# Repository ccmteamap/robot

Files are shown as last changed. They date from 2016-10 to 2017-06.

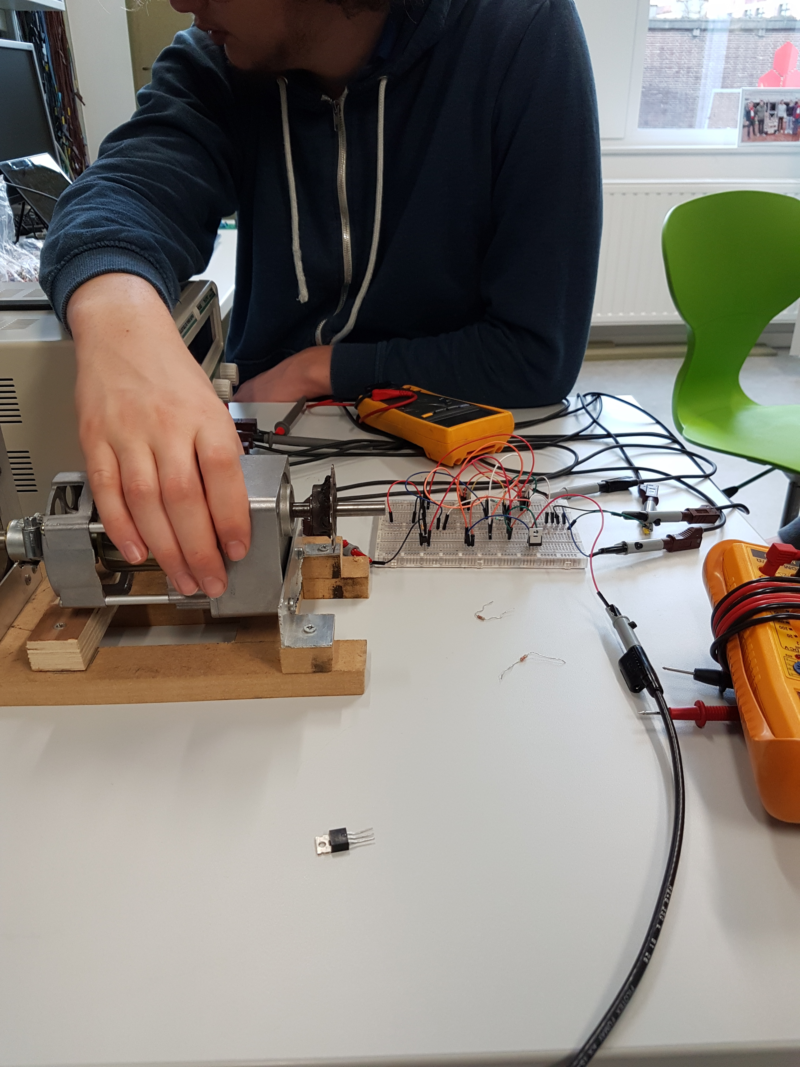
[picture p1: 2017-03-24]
docs/photos/IMG_20170320_091853.jpg

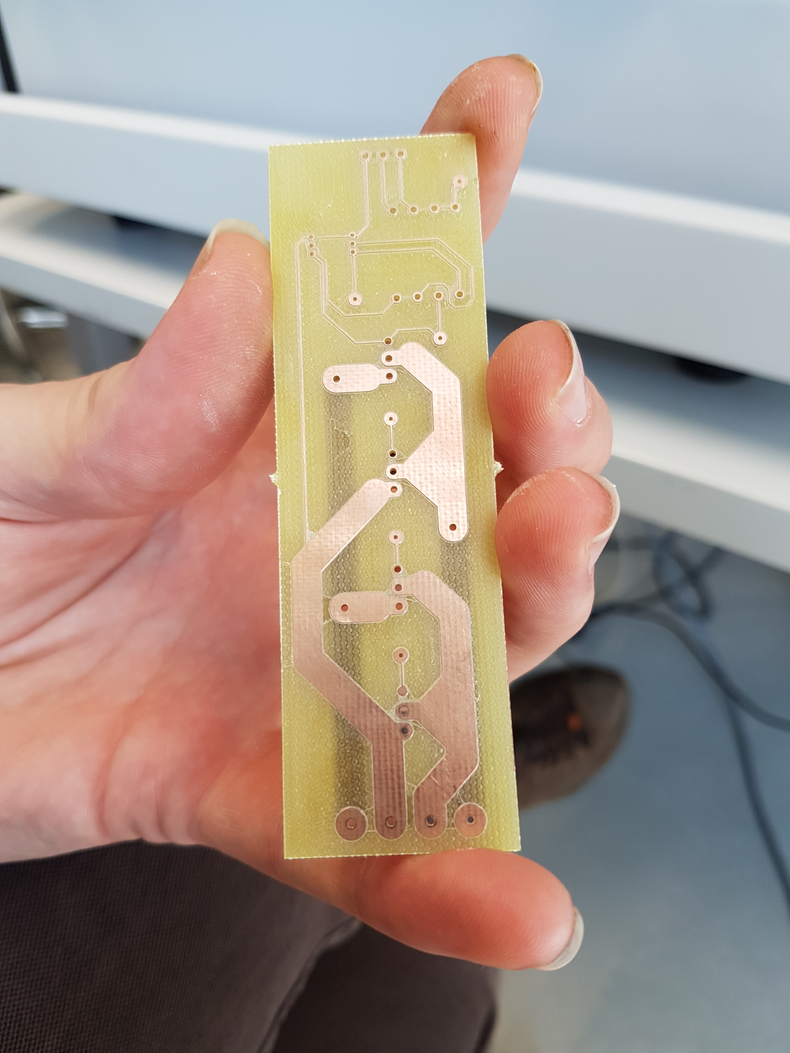
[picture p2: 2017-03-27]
docs/photos/20170327_143319.jpg

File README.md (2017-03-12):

# Project team CCMAP
## Project description
Design and build a robot that drives from the starting position to the water source on the other side of the contest area and fill  bucket with water, drive the bucket with water back through the contest area which has obstacles on the floor and deposit the water in the water collection tower on the “fire” location.
The robot must be working autonomously when it is in the contest area. It is not allowed to “help” the robot while in the contest area. If the robot gets stuck the teams are allowed to stop the robot and move the robot back to the start position from which the robot can be restarted with an empty bucket. The robot can make multiple runs collecting and delivering water within the duration of 5 minutes. The water must be transported in an open bucket, covering the bucket is not allowed, it is not allowed to re-use water spilled from the bucket. It is only allowed to transport the water inside the bucket. 

[More info](http://www.ccm.nl/en/assignment-2017/assignment-2017.html)

## Our team

  We have divided our team into 3 subgroups:
  
  **Driving**
  
  Ski De Keersmaecker
  
  Ruven Salamon
  
  **Bucket**
  
  Robbe Goethals
  
  Wouter Peetermans
  
  **Pump**
  
  Koen Schauwaert
  
  Maarten Wachters

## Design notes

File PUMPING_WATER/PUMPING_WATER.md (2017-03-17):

#TODO

#GOALS

1. Pump water from basin into bucket (without touching the bucket)
2. Transport the water to the other bucket
3. Lifting system that allows the bucket to be lifted and tilted

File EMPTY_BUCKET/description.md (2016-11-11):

#General
This part of the robot will have to empty the bucket, filled with water by the pump, in a reservoir.
The bucket will be attached to some kind of rollercoastercar.
The car will be pulled upwards with the DC-motor using bearings and two rails.

#Design
The rails in wich the car moves will go straight up.
At the end of the rails, they will bend over the reservoir so the bucket can be emptied.
Because the bucket is fixed to the moving car, the bend will enable us to empty the bucket.

#Software

##Master-Arduino
The Arduino used for driving the robot (master)  will communicate to the Arduino for emptying the bucket (slave).
When the master knows that the robot is standing against the reservoir using distance sensors, it will send a signal to the slave so that the filled bucket can be emptied.

##Slow start
To make sure we don't spill a lot of water, the start of the emptying-part will be slow. The motor will start pulling the car upwards.

##Middle
Because time is essential in this assignment, we have a powerfull motor that can pull the bucket fastly to the bended part in the rails.

##Emptying
When the bucket is at the bended part of the rails, water will begin to be poured out of the bucket.
The motor will then slowly pull the car until the end of the rail is reached so the water is poured in the reservoir and nothing is spilled over.

##Empty bucket
When there's no more water in the bucket, the microcontroller will have to send a signal to the master so that the robot can already drive towards the water supply.
While driving, the bucket will be let down back to it's original place.
When the bucket is down, the Arduino will again send a signal to the master so that the master can let the pump fill the bucket again.

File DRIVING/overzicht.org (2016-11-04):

* Onderstel
** MateriaalLijst
- 2 moteren
- 4 wielen (met lagers ?)
- 4 kleine assen
- 2 kettingen / riemen
- 6 afstandsensoren
- arduino's
  - 1 master/emmer/pomp;
  - 1 per 2 sensoren
  => 4 arduino's
- 4 lagers
** Onderdelen
*** Seriële communicatie [0/2]
    - [ ] Protocol kiezen.
      * I2C
      * SPI
    - [ ] Protocol uittesten.	
    - [ ] Custom library schrijven.
*** Sensoren [2/4]
    - [X] Soort sensor kiezen en testen.
      * Ultrasoon
      * Infrarood
    - [X] Opstelling kiezen.
    - [ ] Library schrijven.
      * Cache systeem om foutieve waardes weg te gooien.x
    - [ ] Reactieruimte voor verschillende snelheden bij verschillende hoeken berekenen.
*** Wielaandrijving [/]
*** Frame [0/3]
    - [ ] Wielen kiezen
    - [ ] Ontwerp uittekenen.
      * gewicht andere modules inschatten
      * Monteerpunten voor emmer en pomp
      * Bekabeling
      * Batterij
      * Motor
      * Aandrijving
      * Wielen
      * Sensoren

* TEAMS

| TEAMS | Onderstel | Emmer  | Pomp    |
|-------+-----------+--------+---------|
|       | Ruven     | Wouter | Koen    |
|       | Ski       | Robbe  | Maarten |

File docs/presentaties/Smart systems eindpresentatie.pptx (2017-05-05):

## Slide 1

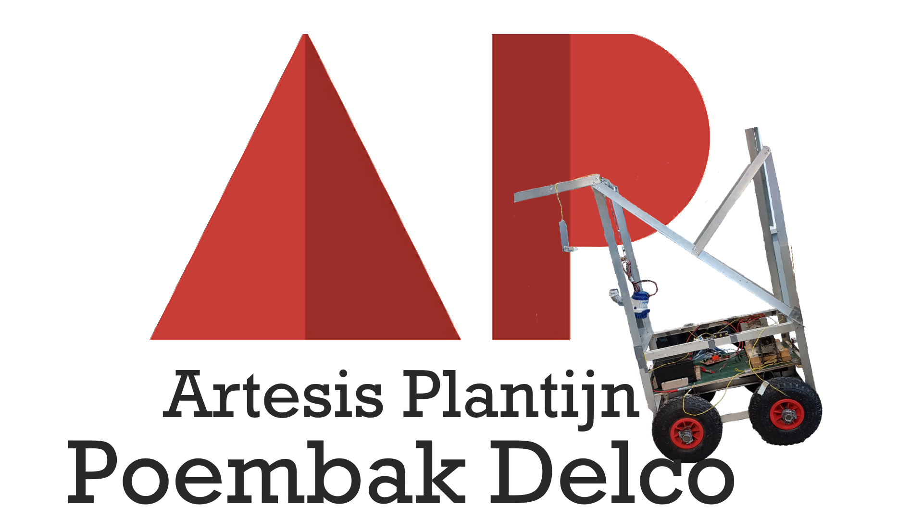
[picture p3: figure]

## Opdracht

## Progress

“Where are ü now” - Diplo

## PCB

## Frame

## Pomp

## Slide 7

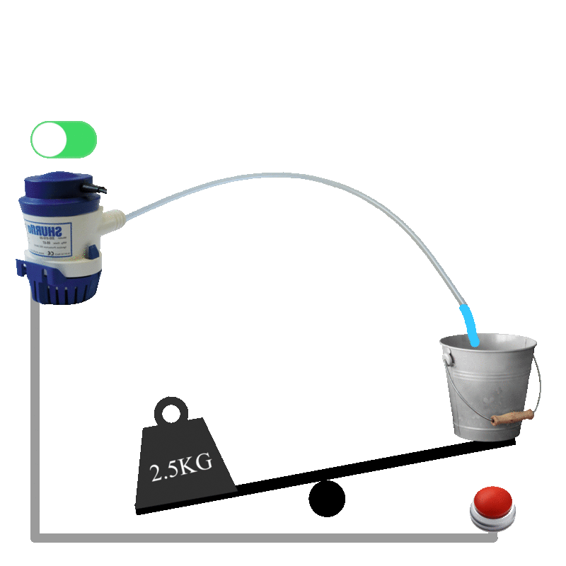
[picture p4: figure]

## Code

## Wedstrijd

CCM/Sioux wedstrijd 17/05/2017

## opdracht

## Opdracht

## Verloop

## Documentatie

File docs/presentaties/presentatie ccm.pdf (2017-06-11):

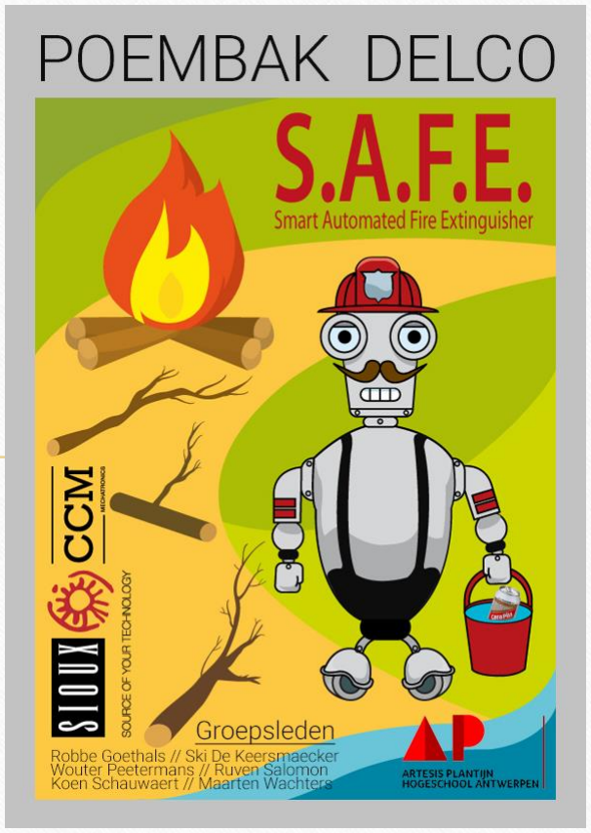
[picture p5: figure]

# Robot CCM

## Poembak delco gaat ervoor

# Analyse probleemstelling

- Hoe krijgen we het water uit de waterbak?
- Hoe krijgen we het water in de emmer?
- Hoe behouden we het water in de emmer tijdens transport?
- Hoe krijgen we het water bij de ‘Fire Location’?
- Hoe rijden we over het parcours?
- Hoe ontwijken we de obstakels?

# Opsplitsing onderdelen

- Team Transport:
- Ruven & Ski
- Aansturen wielen
- Frame
- Team Emmer:
- Wouter & Robbe
- Emmer uitkiepen
- Team Pomp:
- Koen & Maarten
- Emmer vullen

# Team Transport

- 2 krachtige motoren
- Zware schokken opvangen
- Snelheid maken en behouden
- Wielen
- Pros:
- Goedkoop
- Makkelijke implementatie
- Behendig
- Cons:
- Minder schokbestendig

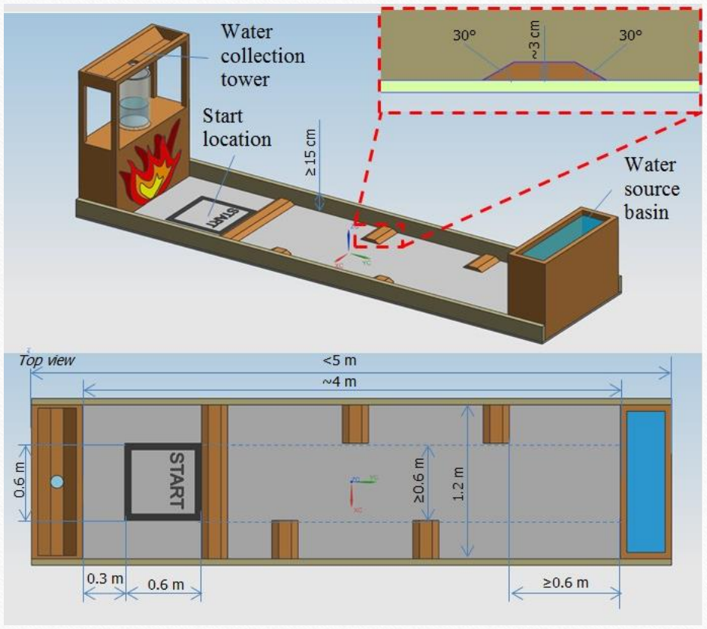
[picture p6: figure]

- Doel:
- Zij obstakels ontwijken
- Robot met wielen max. 50 cm breed
- Groot obstakel afremmen + wielen met dikke banden (schokabsorptie)
- Uitlezen beide basins wanneer stoppen robot en uitkiepen emmer of starten pompen – middels eindloopschakelaar
- 1 minuut per rit: 15 sec. heen en 15 sec. terug: snelheid: 8 meter per 0,5 min = 0,96km/u
- Doel: 2 a 3km/u en afremmen bij obstakel

# Benodigdheden: wat we al hebben

- Motor met reductie voor aandrijving robot
- Assen
- Ketting en tandwielen
- Arduino
- Sensoren

# Benodigdheden: aan te kopen

- Wielen | • 100 euro

# Team Emmer

- Emmer laag in frame voor stabiliteit
- Optakelen via rails (zoals achtbaan: kogellagers klemmen rondom rails)
- Omhoog en omlaag via ketting, aangestuurd door motor
- Bovenaan gebogen rails voor uitschenken emmer

## Test liften emmer

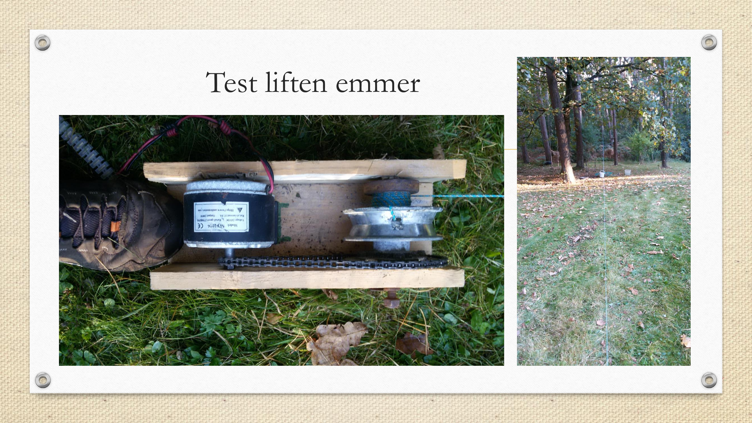
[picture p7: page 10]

# Benodigdheden: wat we al hebben

- Emmer
- Motor voor hijsen van emmersysteem (kar)
- Rails met kogellagers
- Arduino
- Sensoren

# Benodigdheden: aan te kopen

- Niets

# Team Pomp

- Gebruik van dompelpomp
- In basin laten zakken middels katrolsysteem
- Via eindeloopschakelaar in laten pompen en pomp laten zakken wanneer robot tegen basin

# Benodigdheden: wat we al hebben

- Arduino
- Sensoren

# Benodigdheden: aan te kopen

- Dompelpomp
- Katrolsysteem
- Motor
- Tuinslang met koppelstukjes
- 50 euro
- 5 euro
- 100 euro
- 15 euro

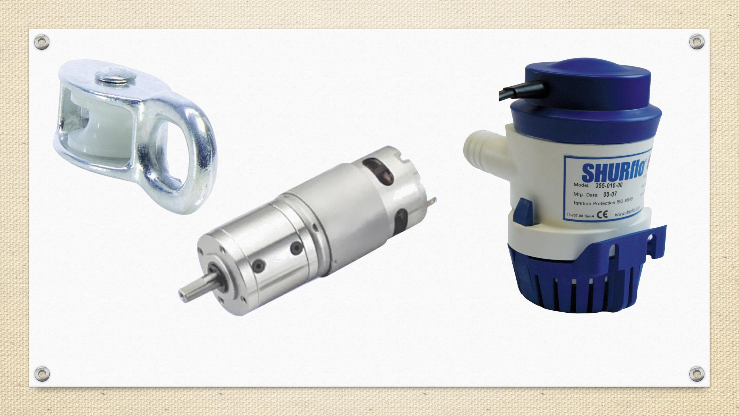
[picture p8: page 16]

# Programmatie

//calculates a new exponential moving average.

unsigned int calcAverage(unsigned int distance, unsigned long average) {

static float smoothingFactor = 2.0 / (SAMPLESIZE + 1.0);

double newAverage = (distance * smoothingFactor) + (average * (1

- smoothingFactor));

return round(newAverage);

}

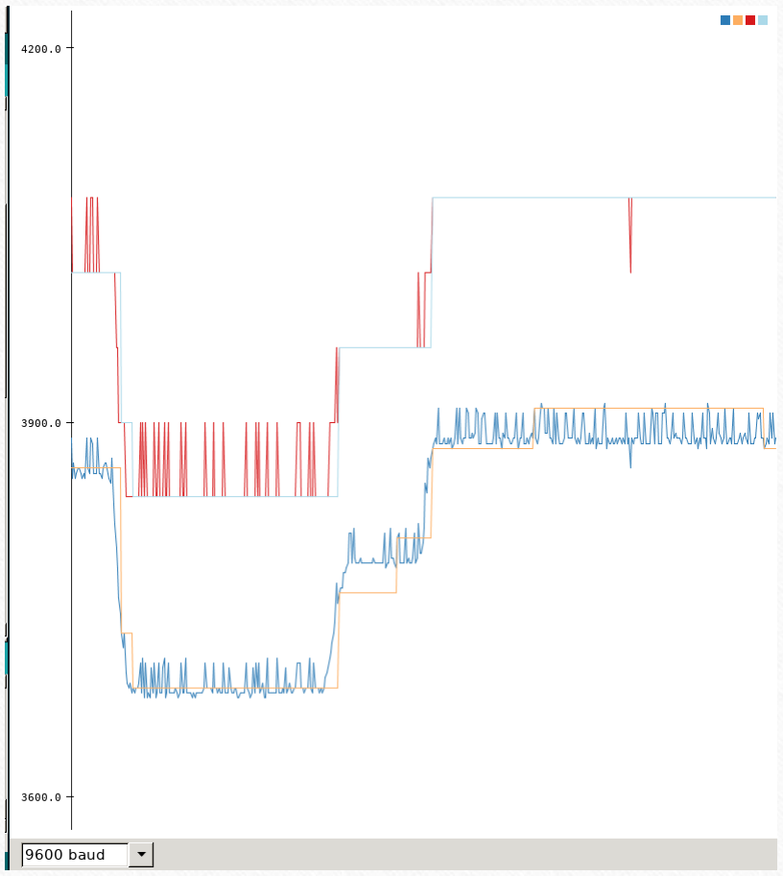
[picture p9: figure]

- Rood: ruwe meting in cm
- Lichtblauw: exponential moving avg.
- Gebruik voor elke sensor

# Benodigdheden: wat we al hebben algemeen

- Groot gedeelte van het frame van vorig jaar
- Arduino
- Sensoren
- Oplader voor de batterijen

# Benodigdheden: aan te kopen algemeen

- Klinknagels
- Deel van het frame
- Batterijen
- Kogellagers reserve
- 35 euro voor 100 stuks
- 100 euro
- 100 euro voor 4 stuks (2 x reserve)
- 36 euro voor 10 stuks

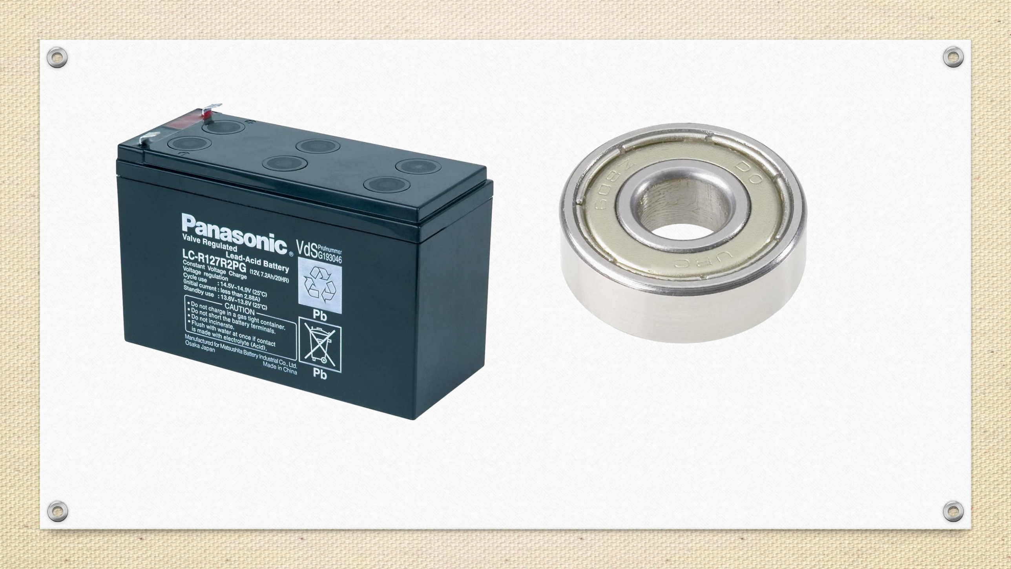
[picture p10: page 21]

# Kostenraming

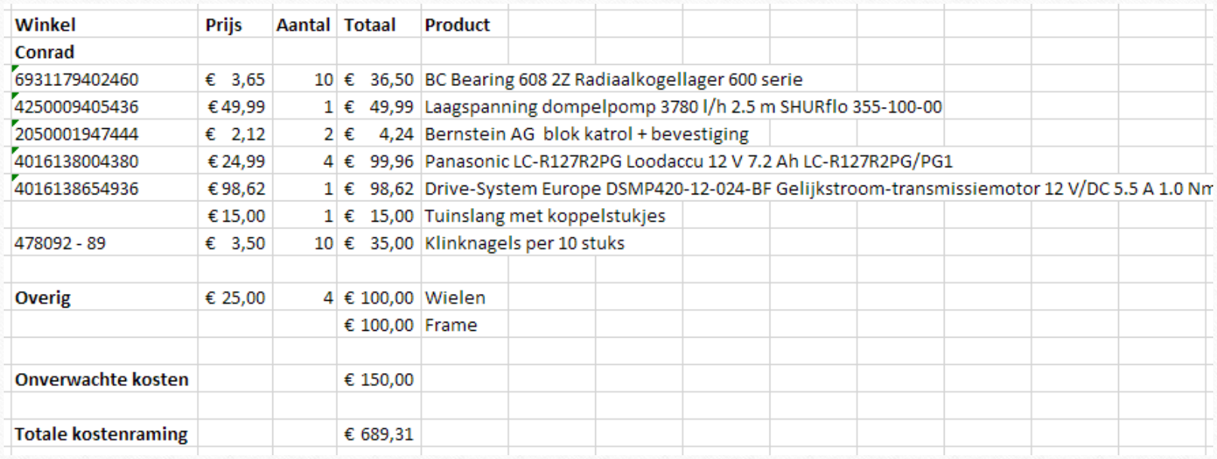
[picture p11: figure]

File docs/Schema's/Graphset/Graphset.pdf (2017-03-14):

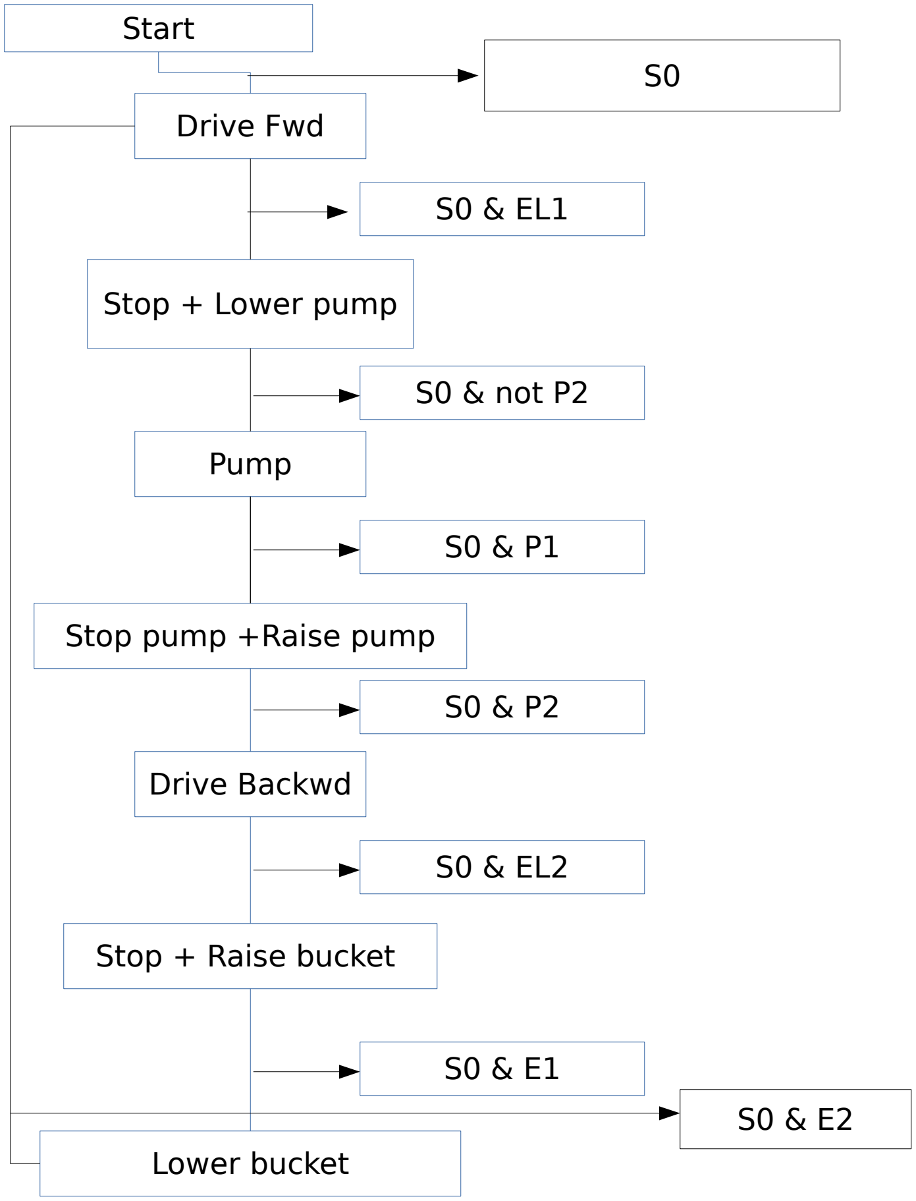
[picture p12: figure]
Drive Fwd; Stop + Lower pump; Pump; Stop pump +Raise pump; Drive Backwd; Stop + Raise bucket; Lower bucket; Start; S0 & not P2

E1: Emmer bovenaan
E2: Emmer onderaan
EL1 : Eindeloopschakelaar emmer zijde EL2: Eindeloopschakelaar pomp zijde P1: Pomp aan emmer
P2: Pomp aan kraan(?)
S0: Start

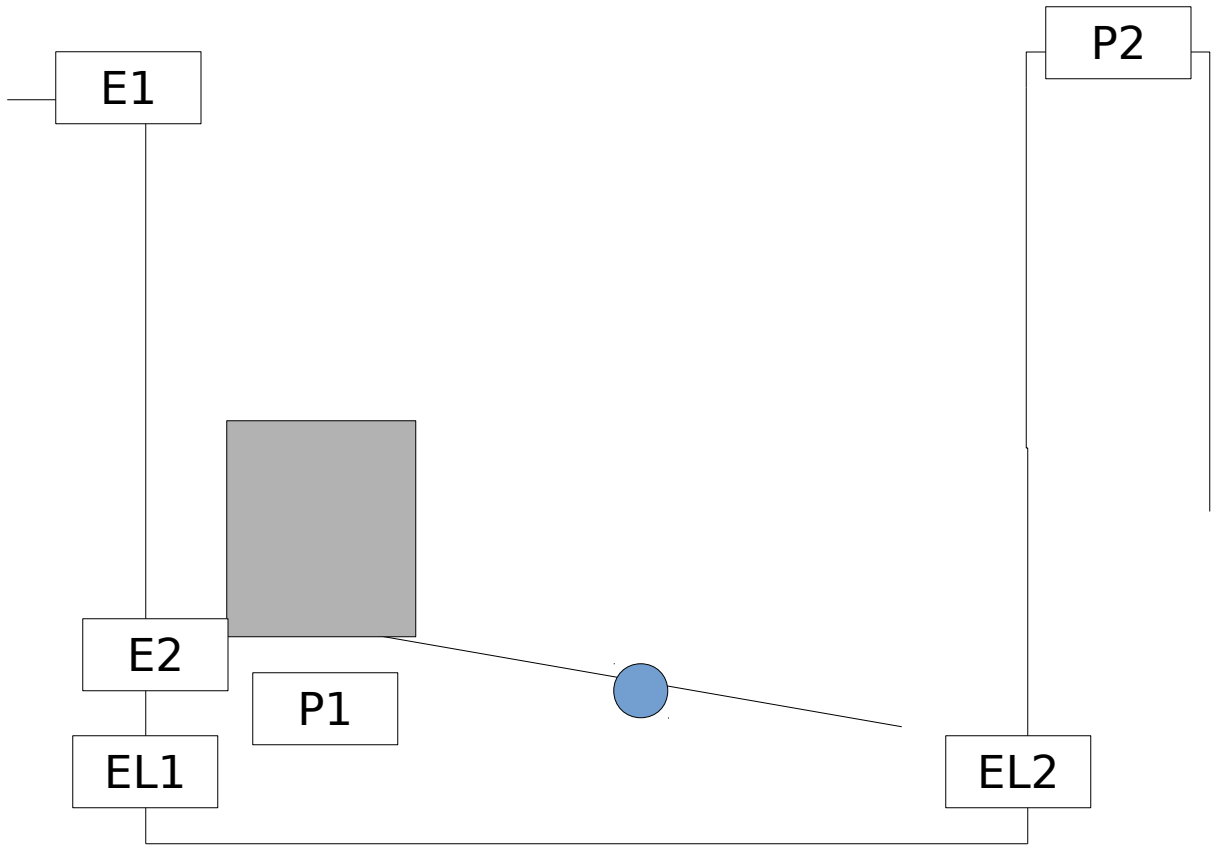
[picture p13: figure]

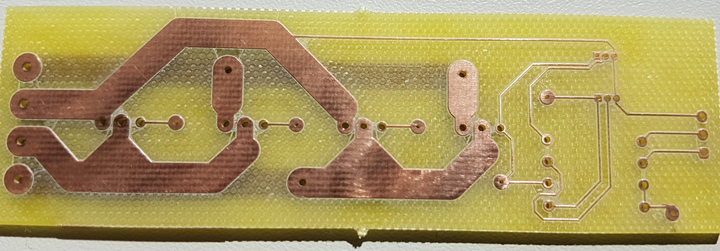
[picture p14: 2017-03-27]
docs/photos/pcb.png

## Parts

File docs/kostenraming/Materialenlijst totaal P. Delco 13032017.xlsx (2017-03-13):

Winkel | Prijs | Aantal | Totaal | Product | URL
Conrad
4250009405436 | €49.99 | 1 | €49.99 | Laagspanning dompelpomp 3780 l/h 2.5 m SHURflo 355-100-00 | https://www.conrad.nl/nl/laagspanning-dompelpomp-3780-lh-25-m-shurflo-355-100-00-551121.html
2050001947444 | €2.12 | 5 | €10.60 | Bernstein AG blok katrol + bevestiging | https://www.conrad.nl/nl/bernstein-ag-bevestiging-voor-blok-katrol-bevestiging-voor-blokkatrol-1-stuks-1164845.html
4016138004380 | €24.99 | 4 | €99.96 | Panasonic LC-R127R2PG Loodaccu 12 V 7.2 Ah LC-R127R2PG/PG1 | https://www.conrad.nl/nl/panasonic-lc-r127r2pg-loodaccu-12-v-72-ah-lc-r127r2pgpg1-loodvlies-agm-b-x-h-x-d-151-x-94-x-65-mm-kabelschoen-48-mm-onderhoudsvrij-vd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
4016138654936 | €98.62 | 1 | €98.62 | Drive-System Europe DSMP420-12-024-BF Gelijkstroom-transmissiemotor 12 V/DC 5.5 A 1.0 Nm 248 omw/min As-diameter: 8 mm Drive-System Europe | https://www.conrad.nl/nl/drive-system-europe-dsmp420-12-024-bf-gelijkstroom-transmissiemotor-12-vdc-55-a-10-nm-248-omwmin-as-diameter-8-mm-191880.html
533468 - 89 | €5.99 | 5 | €29.95 | Weefselslang 1 1/4 inch Transparant | https://www.conrad.nl/nl/weefselslang-1-14-inch-transparant-533468-533468.html
1008392 - 89 | €6.99 | 1 | €6.99 | Sanifri 470010476 Slangklem Set van 10 | https://www.conrad.nl/nl/sanifri-470010476-slangklem-set-van-10-1008392.html
478092 - 89 | €3.50 | 10 | €35.00 | Klinknagels per 10 stuks | https://www.conrad.nl/nl/bralo-klinknagelmoer-roestvrij-staal-platbolkop-ronde-schacht-open-95-mm-roestvrij-staal-aisi-304-10-stuks-478092.html
1005174 - 89 | €4.79 | 1 | €4.79 | Soudal Silirub S Siliconen Kleur: Transparant 310 ml | https://www.conrad.nl/nl/soudal-silirub-s-siliconen-kleur-transparant-310-ml-1005174.html
404198 - 89 | €4.79 | 2 | €9.58 | TOOLCRAFT Gaffer Textieltape Grijs (l x b) 20 m x 48 mm Smeltlijm Inhoud: 1 rollen | https://www.conrad.nl/nl/toolcraft-gaffer-textieltape-grijs-l-x-b-20-m-x-48-mm-smeltlijm-inhoud-1-rollen-404198.html
541124 - 89 | €1.29 | 2 | €2.58 | Conrad Components Isolatietape Zwart (l x b) 10 m x 19 mm Rubber Inhoud: 1 rollen | https://www.conrad.nl/nl/conrad-components-isolatietape-zwart-l-x-b-10-m-x-19-mm-rubber-inhoud-1-rollen-541124.html
600409 - 89 | €1.04 | 10 | €10.40 | LappKabel 0052001 Hoge-temperatuur-draad ÖLFLEX® HEAT 180 SIF 1 x 2.5 mm² Zwart Per meter | https://www.conrad.nl/nl/lappkabel-0052001-hoge-temperatuur-draad-oelflex-heat-180-sif-1-x-25-mm-zwart-per-meter-600409.html
603167 - 89 | €0.94 | 10 | €9.40 | LappKabel 0052104 Hoge-temperatuur-draad ÖLFLEX® HEAT 180 SIF 1 x 2.5 mm² Rood Per meter | https://www.conrad.nl/nl/lappkabel-0052104-hoge-temperatuur-draad-oelflex-heat-180-sif-1-x-25-mm-rood-per-meter-603167.html
1225410 - 89 | €0.18 | 5 | €0.90 | Krimpkous zonder lijm Zwart 1 mm Krimpverhouding:2:1 | https://www.conrad.nl/nl/krimpkous-zonder-lijm-zwart-1-mm-krimpverhouding21-1225410.html
1225442 - 89 | €0.20 | 5 | €1.00 | Krimpkous zonder lijm Zwart 2.50 mm Krimpverhouding:2:1 | https://www.conrad.nl/nl/krimpkous-zonder-lijm-zwart-250-mm-krimpverhouding21-1225442.html
1225453 - 89 | €0.24 | 5 | €1.20 | Krimpkous zonder lijm Zwart 4.50 mm Krimpverhouding:2:1 | https://www.conrad.nl/nl/krimpkous-zonder-lijm-zwart-450-mm-krimpverhouding21-1225453.html
1225446 - 89 | €0.24 | 5 | €1.20 | Krimpkous zonder lijm Rood 4.50 mm Krimpverhouding:2:1 | https://www.conrad.nl/nl/krimpkous-zonder-lijm-rood-450-mm-krimpverhouding21-1225446.html
214477 - 89 | €2.49 | 20 | €49.80 | Radiaal kogellager van chroomstaal 7 mm | https://www.conrad.nl/nl/radiaal-kogellager-van-chroomstaal-7-mm-214477.html
1340437 - 89 | €9.99 | 2 | €19.98 | Loodaccu-lader VOLTCRAFT BC-600 2 V, 6 V, 12 V Loodgel, Loodzuur, Loodvlies | https://www.conrad.nl/nl/loodaccu-lader-voltcraft-bc-600-2-v-6-v-12-v-loodgel-loodzuur-loodvlies-1340437.html
812371 - 89 | €3.29 | 2 | €6.58 | WD40 Company 49201 WD-40 Multi-olie 100 ml | https://www.conrad.nl/nl/wd40-company-49201-wd-40-multi-olie-100-ml-812371.html
478006 - 89 | €2.69 | 2 | €5.38 | Bralo Klinknagel alu/staal platbolkop kleinverpakking 8 mm Aluminium/staal 50 stuks | https://www.conrad.nl/nl/bralo-klinknagel-alustaal-platbolkop-kleinverpakking-8-mm-aluminiumstaal-50-stuks-478006.html
1493521 - 89 | €9.62 | 8 | €76.96 | Panasonic AM1301F Eindschakelaar 250 V/AC 10 A Metalen hefboom, recht schakelend IP40 1 stuks | https://www.conrad.nl/nl/panasonic-am1301f-eindschakelaar-250-vac-10-a-metalen-hefboom-recht-schakelend-ip40-1-stuks-1493521.html
Brico
4001073199208 | €21.24 | 4 | €84.96 | Wagner pneumatisch wiel diam. 200 mm | https://www.brico.be/search?text=Wagner+pneumatisch+wiel+diam.+200+mm
Totale kostenraming |  |  | €615.82

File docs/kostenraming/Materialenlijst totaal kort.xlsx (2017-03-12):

Winkel | Prijs | Aantal | Totaal | Product
Conrad
6931179402460 | €3.65 | 10 | €36.50 | BC Bearing 608 2Z Radiaalkogellager 600 serie
4250009405436 | €49.99 | 1 | €49.99 | Laagspanning dompelpomp 3780 l/h 2.5 m SHURflo 355-100-00
2050001947444 | €2.12 | 2 | €4.24 | Bernstein AG blok katrol + bevestiging
4016138004380 | €24.99 | 4 | €99.96 | Panasonic LC-R127R2PG Loodaccu 12 V 7.2 Ah LC-R127R2PG/PG1
4016138654936 | €98.62 | 1 | €98.62 | Drive-System Europe DSMP420-12-024-BF Gelijkstroom-transmissiemotor 12 V/DC 5.5 A 1.0 Nm 248 omw/min As-diameter: 8 mm Drive-System Europe
533468 - 89 | €5.99 | 5 | €29.95 | Weefselslang 1 1/4 inch Transparant
1008392 - 89 | €6.99 | 1 | €6.99 | Sanifri 470010476 Slangklem Set van 10
478092 - 89 | €3.50 | 10 | €35.00 | Klinknagels per 10 stuks
1005174 - 89 | €4.79 | 1 | €4.79 | Soudal Silirub S Siliconen Kleur: Transparant 310 ml
404198 - 89 | €4.79 | 2 | €9.58 | TOOLCRAFT Gaffer Textieltape Grijs (l x b) 20 m x 48 mm Smeltlijm Inhoud: 1 rollen
541124 - 89 | €1.29 | 2 | €2.58 | Conrad Components Isolatietape Zwart (l x b) 10 m x 19 mm Rubber Inhoud: 1 rollen
600409 - 89 | €1.04 | 10 | €10.40 | LappKabel 0052001 Hoge-temperatuur-draad ÖLFLEX® HEAT 180 SIF 1 x 2.5 mm² Zwart Per meter
603167 - 89 | €0.94 | 10 | €9.40 | LappKabel 0052104 Hoge-temperatuur-draad ÖLFLEX® HEAT 180 SIF 1 x 2.5 mm² Rood Per meter
1225410 - 89 | €0.18 | 5 | €0.90 | Krimpkous zonder lijm Zwart 1 mm Krimpverhouding:2:1
1225442 - 89 | €0.20 | 5 | €1.00 | Krimpkous zonder lijm Zwart 2.50 mm Krimpverhouding:2:1
1225453 - 89 | €0.24 | 5 | €1.20 | Krimpkous zonder lijm Zwart 4.50 mm Krimpverhouding:2:1
1225446 - 89 | €0.24 | 5 | €1.20 | Krimpkous zonder lijm Rood 4.50 mm Krimpverhouding:2:1
Overig | €25.00 | 4 | €100.00 | Wielen
 |  |  | €100.00 | Frame
Totale kostenraming |  |  | €602.30

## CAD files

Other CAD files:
3D_MODELS/Inventor/Frame.ipt
3D_MODELS/Inventor/OldVersions/Frame.0002.ipt
3D_MODELS/Inventor/OldVersions/VolledigGeassembleerdv001.0016.iam
3D_MODELS/Inventor/OldVersions/aandrijfMotor.0002.ipt
3D_MODELS/Inventor/OldVersions/asKogellager.0001.ipt
3D_MODELS/Inventor/OldVersions/emmer.0001.ipt
3D_MODELS/Inventor/OldVersions/emmerhouder.0002.ipt
3D_MODELS/Inventor/OldVersions/ketting1.0001.ipt
3D_MODELS/Inventor/OldVersions/ketting2.0001.ipt
3D_MODELS/Inventor/OldVersions/touw1.0003.ipt
3D_MODELS/Inventor/OldVersions/wiel.0001.ipt
3D_MODELS/Inventor/OldVersions/wiel.0003.ipt
3D_MODELS/Inventor/OldVersions/winch.0001.ipt
3D_MODELS/Inventor/VolledigGeassembleerdv001.iam
3D_MODELS/Inventor/VolledigGeassembleerdvTekening.idw
3D_MODELS/Inventor/aandrijfMotor.ipt
3D_MODELS/Inventor/as.ipt
3D_MODELS/Inventor/asKogellager.ipt
3D_MODELS/Inventor/batterij.ipt
3D_MODELS/Inventor/emmer.ipt
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

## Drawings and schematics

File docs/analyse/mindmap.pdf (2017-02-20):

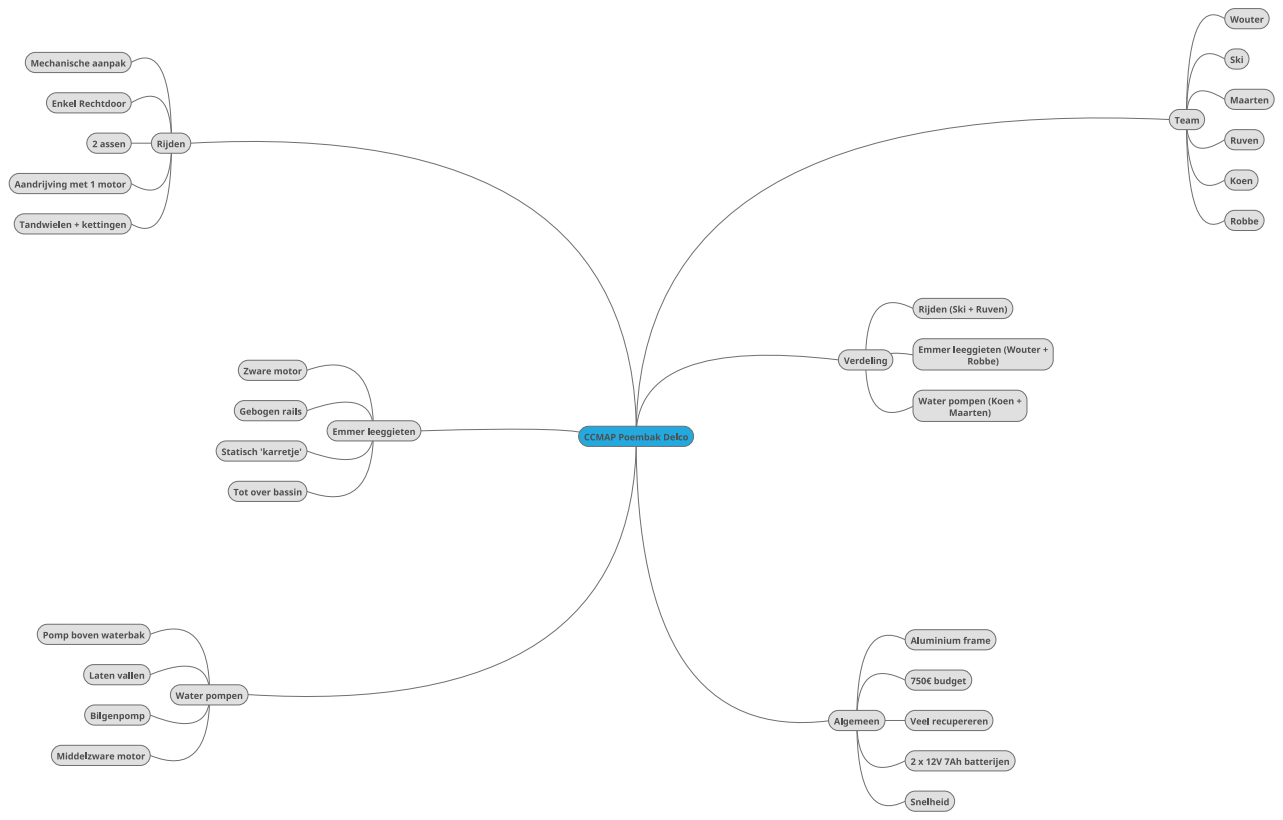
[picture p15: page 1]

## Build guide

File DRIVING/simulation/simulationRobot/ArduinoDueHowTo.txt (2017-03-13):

Installeer nieuwste versie van Arduino (min 1.6)

Installeer driver voor Arduino DUE, via 'hulpmiddelen' => 'Board' => 'Bordenbeheerder' => invullen 'Arduino DUE' en pakket installeren.

Steek kabel in de poort het dichtst bij de voeding (kant van analoge pinnen).

Kies voor board: "Arduino Due (programming port)"

Kies voor poort degene die wordt getoond => iets als: "COM4 (Arduino Due (programming port))"

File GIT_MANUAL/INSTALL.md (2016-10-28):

## How to get the repo
	1. Make Git Bash.
	2. Execute command : 'git clone https://github.com/ccmteamap/robot'

## If the repo did not clone
	1. Execute command : 'git remote add origin https://github.com/ccmteamap/robot'  

##	Pull & push

	1. Pull the git : 'git pull origin master'
	2. Push the git : 'git push origin master'

## ssh toegang (geen paswoorden invoeren bij elke push)

	1. genereer een keypaar : 'ssh-keygen'    (let goed op waar je deze opslaagt je hebt ze nodig)
	2. kopieer de publieke sleutel (ssh_id.pub)
	3. open github settings en ga naar 'ssh and GPG keys'
	4. klik op new ssh key
	5. plak de sleutel en saven die handel
	6. delete de huidige origin : 'git remote remove origin'
	7. maak een nieuwe origin aan : 'git remote add origin git@github.com:ccmteamap/robot.git'

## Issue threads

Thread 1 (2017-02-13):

As a <customer>, I want <a detailed mechanical drawing> so <I can see the thought process and working behind the robot>

themaawaa, 2017-02-13:
**User Story**
 As a *customer*
 I *want a detailed mechanical drawing*
 so I _understand the idea and the concept of the robot_

**Acceptance Criteria**
 Make an inventor model that is detailed about (roller) bearings, dimensions of the frame, a more thought out moving process of the bucket.

**Definition of done**
 The model is done and incorporated in the presentation

Closed 2017-06-08.

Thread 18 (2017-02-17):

As a team we want the robot to be max. 50cm wide to avoid the side obstacles

koenschauwaert, 2017-02-17:
- [ ] acquire materials
- [ ] cut frame so that with weels the width of the frame is 50cm
- [ ] build the frame
- [ ] attach axis for the weels on frame
- [ ] attach weels so that width doesn't exceed 50cm

Closed 2017-06-08.

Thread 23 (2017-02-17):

[EPIC] As a team we want the robot to extract water out of the basin into the bucket

koenschauwaert, 2017-02-17:
**User Story**

**Acceptance Criteria**

**Definition of done**

koenschauwaert, 2017-02-24:
- [ ] Buy a pump
- [ ]
- [ ]
- [ ]

Closed 2017-06-08.

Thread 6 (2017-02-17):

As a customer I want a clear overview of a prototype in Inventor which shows the operation

koenschauwaert, 2017-02-17:
- [ ] test

RuvenSalamon, 2017-02-26:
- [ ] Merge designs and implementation ideas from different groups into one grand design.
- [ ] Draw design in Inventor.
- [ ] Add arrows to indicate which motions will take place during normal operation.
- [ ] Take screenshots of the different stages of operation.

Closed 2017-06-08.

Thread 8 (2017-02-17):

As a customer I want a detailed cost estimation with a maximum of 750 euro

koenschauwaert, 2017-02-17:
- [ ] test

RuvenSalamon, 2017-02-26:
- [ ] Break down project into parts that have a discrete functionality.
- [ ] Find ways to implement those functionalities.
- [ ] Write down the material needed to create those implementations.
- [ ] Look up current market prices of those materials.
- [ ] Combine all the estimations and see if it exceeds the maximum budget.
- [ ] If it exceeds, find ways to cut down the costs or research different implementations.

Closed 2017-06-08.

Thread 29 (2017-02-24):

As a team we want to program the software for Arduino to read-out sensors and start motors etc.

koenschauwaert, 2017-02-24:
- [ ] test

RuvenSalamon, 2017-03-31:
zelfde als issue #30

Closed 2017-06-08.

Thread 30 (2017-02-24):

As a team we want to program the software for Arduino to read-out sensors and start motors etc.

koenschauwaert, 2017-02-24:
- [ ] test

RuvenSalamon, 2017-03-13:
- [ ] initialize pins
- [ ] create Motor class
- [ ] read out sensors
- [ ] adjust state to readings.

RuvenSalamon, 2017-03-31:
zelfde als issue #31

Closed 2017-06-08.

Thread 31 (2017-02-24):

As a team we want to program the software for Arduino to read-out sensors and start motors etc.

koenschauwaert, 2017-02-24:
- [ ] design electrical circuit
- [x] design graphset diagram
- [ ] build electrical circuit on arduino
- [ ] test circuit with simple components (LED, sensors, ...)
- [x] software for starting motor
- [x] software for reading out sensors
- [x] software for driving forward
- [x] software for stopping
- [x] software for driving backward
- [x] software for reacting to sensorvalues
- [x] software for looping driving cycle

Closed 2017-06-08.

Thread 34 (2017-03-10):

As a team we want to imitate the build of the track, so we can practice on our own.

koenschauwaert, 2017-03-10:
- [x] get wood
- [x] mark the wood where to saw
- [x] build the water basin
- [x] build the fire location
- [x] build the obstacles (4x 30cm, 1x 120cm)
- [ ] complete the track by adding everything together

Closed 2017-06-08.

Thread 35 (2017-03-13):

As a programmer I want my robot to have wireless communication so I can have real time debugging information.

RuvenSalamon, 2017-03-13:
**User Story**

**Acceptance Criteria**

**Definition of done**

RuvenSalamon, 2017-03-13:
- [ ] attach nRF24 radio transmitter to Arduino
- [ ] attch nRF24 radio receiver to Arduino and that Arduino to a laptop
- [ ] write software that allows them to communicate
- [ ] gather robot state information and real time feedback on the general operation
- [ ] send it

Closed 2017-06-08.

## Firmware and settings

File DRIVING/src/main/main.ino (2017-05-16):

/*
   Team Poembak Delco
   AP Hogeschool
   2017
*/
#include"main.h" //interface om robot aan/uit/pauze te zetten
#include"sensors.h" //nodig om de sensormask te krijgen
#include"comm.h" //kijken of er instructie zijn ontvangen.
#include"parser.h" //nodig om ontvangen instructies te ontleden
#include"debug.h"//nodig om debug informatie door te laten sturen
#include"motor.h"
#include<stdint.h>

bool running;
State currentState = Off;
int sensorMask = 0;

void setup() {
  Serial.begin(9600);
  initSensorPins();
  startComm();
}

void loop() {
  inputScan(); //update status of sensors.
  executeProgram(); //update state and perform action
  callHome(); //send debugging information.
  listenHome(); //see if we got instructions.
}

void listenHome() {
  uint8_t buffer[PAYLOAD_SIZE];

  if(read(buffer, PAYLOAD_SIZE)){
    Serial.print("Received: ");
    Serial.println((char*)buffer);
    parse(buffer);
  }
}

void callHome() {
  debug();
}

void inputScan() {
  sensorMask = getSensorMask();
  measureDistances();
}

void executeProgram() {
  updateState();
  stateAction();
}

void updateState() { //GETEST
  switch (currentState) {
    case Off:
      if(running){
        currentState = DrivingForward;
      }
      break;

    //Als 'aan' en eindeloopschakelaar pompzijde ingedrukt
    case DrivingForward:
      if (sensorMask & ELOOPPOMP && running) {
	stopDriving();
        currentState = LoweringPump;
      }
      break;

    //Als 'aan' en pompsensor emmer zijn ingedrukt (dus emmer is vol)
    case LoweringPump:
      if (sensorMask & POMP1 && running) {
	stopLowerPump();
        currentState = RaisingPump;
      }
      break;

    //Als 'aan' en pompsensor bassin zijn ingedrukt (dus pomp is opgehaald)
    case RaisingPump:
      if (sensorMask & POMP2 && running){
	stopRaisePump();
        currentState = DrivingBackwards;
      }
      break;

    //Als 'aan' en eindeloopschakelaar emmer zijde ingedrukt (robot tegen vuur zijde)
    case DrivingBackwards:
      if (sensorMask & ELOOPEMMER && running) {
	      stopDriving();
        currentState = RaisingBucket;
      }
      break;

    //Als 'aan' en emmer sensor bovenaan ingedrukt (emmer is dus opgehoffen)
    case RaisingBucket:
      if (sensorMask & EMMER1 && running) {
	      stopRaiseBucket();
        currentState = LoweringBucket;
        delay(1000);
      }
      break;

    case LoweringBucket:
      if (sensorMask & EMMER2 && running) {
	      stopLowerBucket();
        currentState = DrivingForward;
      }
      break;

    default:
      //send state
      break;
  }
}

//GETEST
void stateAction() {
  switch (currentState) {
    case DrivingForward:
      drive(true);
      break;

    case LoweringPump:
      lowerPump();
      break;

    case RaisingPump:
      raisePump();
      break;

    case DrivingBackwards:
      drive(false);
      break;

    case RaisingBucket:
      raiseBucket();
      break;

    case LoweringBucket:
      lowerBucket();
      drive(true);
      break;
  }
}

void pause(){
  running = false;
  stopMotors();
}

void run(){
  running = true;
}

void stop(){
  running = false;
  currentState = Off;
  stopMotors();
}

State getState(){
  return currentState;
}

void stopMotors(){
  mainMotor.SetSpeed(0);
  emmerMotor.SetSpeed(0);
  pompMotor.SetSpeed(0);
}

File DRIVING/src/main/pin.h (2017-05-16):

#ifndef PINS_H
#define PINS_H

#define SCK_PIN 52
#define MOSI_PIN 51
#define MISO_PIN 50
#define CE_PIN 48
#define CSN_PIN 49

#define POMP_ULTRA_ECHO_PIN 22
#define POMP_ULTRA_TRIGGER_PIN 24
#define EMMER_ULTRA_ECHO_PIN 26
#define EMMER_ULTRA_TRIGGER_PIN 28

#define POMP_MOTOR_BACKWARDS_PIN 13
#define POMP_MOTOR_FORWARDS_PIN 12
#define EMMER_MOTOR_BACKWARDS_PIN 10
#define EMMER_MOTOR_FORWARDS_PIN 9
#define MAIN_MOTOR_BACKWARDS_PIN 7
#define MAIN_MOTOR_FORWARDS_PIN 6

#define EMMER_ONDER_PIN 38
#define EMMER_BOVEN_PIN 39
#define POMP_ONDER_PIN 40
#define POMP_BOVEN_PIN 41
#define EMMER_ZIJDE_PIN 42
#define POMP_ZIJDE_PIN 43

#endif

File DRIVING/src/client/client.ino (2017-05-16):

#include"comm.h"
#include"debug.h"
#include"sensors.h"
#include"states.h"
#include<string.h>
#include<stdlib.h>

void setup() {
  Serial.begin(9600);
  startComm();
}

void loop() {
  checkSerial(); //see if we received data on the serial connection
  checkRF(); //see if we received data on the wireless connection
}

void checkSerial() {
  if (Serial.available()) {
    handleInput();
  }
}

//GETEST
void handleInput() {
  static char buffer[PAYLOAD_SIZE];
  static int index;

  while (Serial.available()) {
    char symbol = Serial.read();
    if (symbol == '\n') {
      buffer[index] = '\0';

      if (isValidInstruction(buffer)) {
        if (!send(buffer, sizeof buffer)) {
          Serial.println("COMMUNICATION ERROR: could not send instruction.");
        }
        else {
          Serial.println("Instruction send.");
        }
      }

      else {
        Serial.println("SYNTAX ERROR: not a valid instruction.");
      }

      index = 0;
    }

    else if (index < PAYLOAD_SIZE - 1) { //- 1 want laatste plaats in buffer is voor newline
      if (symbol != ' ' && symbol != '\t') {
        buffer[index++] = symbol;
      }
    }

    else {
      Serial.println("SYNTAX ERROR: instruction too long.");
      index = 0;
    }
  }
}

//GETEST
bool isValidInstruction(char *instruction) {
  if (containsChar("RPS", *instruction) ||
      isValidDebugInstruction(instruction) ||
      isValidMotorInstruction(instruction)) {
    return true;
  }
  else {
    return false;
  }
}

//GETEST
bool isValidDebugInstruction(char *instruction) {
  if (*instruction == 'D') {
    while (*++instruction) {
      if (!containsChar("STAM", *instruction)) {
        return false;
      }
    }

    return true;
  }

  else {
    return false;
  }
}

//GETEST
bool isValidMotorInstruction(char *instruction) {
  if (*instruction == 'M' && *(instruction + 1) - '0' >= 0 && *(instruction + 1) - '0' <= 2) {
    instruction += 2;

    if (containsChar("SP", *instruction)) {
      int value = atoi(instruction + 1);

      if (*instruction == 'S') {
        return value <= 255 && value >= -255;
      }

      else if (*instruction == 'P') {
        return value <= 100 && value >= 0;
      }
    }

    else {
      return false;
    }
  }

  else {
    return false;
  }
}

//GETEST
void checkRF() {
  Debug_Message message;
  if (read(&message, sizeof message)) {
    switch (message.type) {
      case DEBUG_START:
        Serial.print("");
        break;
      
      case DEBUG_STOP:
        Serial.println("");
        break;
        
      case DEBUG_MOTOR:
        printMotorInfo(message.body.motorInfo);
        break;

      case DEBUG_DISTANCE:
        printDistanceInfo(message.body.distanceInfo);
        break;

      case DEBUG_STATE:
        printStateInfo(message.body.stateInfo);
        break;

      case DEBUG_SENSORS:
        printSensorsInfo(message.body.sensorsInfo);
        break;
    }
  }
}

//GETEST
void printMotorInfo(Motor_Info info) {
  static const char *motorIds[] = {
    "m",
    "e",
    "p"
  };

  Serial.print("Motor ");
  Serial.print(motorIds[info.id]);
  Serial.print(": ");

  Serial.print("speed: ");
  Serial.print(info.speed);
  Serial.print(" power: ");
  Serial.println(info.power);
}

//GETEST
void printDistanceInfo(Distance_Info info) {
  Serial.print("Afstand emmer: ");
  Serial.print(info.emmerDistance);
  Serial.print(", afstand pomp: ");
  Serial.println(info.pompDistance);
}

//GETEST
void printStateInfo(State_Info info) {
  Serial.print("State: ");
  switch (info.state) {
    case Off:
      Serial.println("Off");
      break;
    case DrivingForward:
      Serial.println("DrivingForward");
      break;
    case LoweringPump:
      Serial.println("LoweringPump");
      break;
    case RaisingPump:
      Serial.println("RaisingPump");
      break;
    case DrivingBackwards:
      Serial.println("DrivingBackwards");
      break;
    case RaisingBucket:
      Serial.println("RaisingBucket");
      break;
    case LoweringBucket:
      Serial.println("LoweringBucket");
      break;
  }
}

//GETEST
void printSensorsInfo(Sensors_Info info) {
  Serial.print("Sensormask: ");
  Serial.print(info.sensorMask);
  Serial.print(" (");

  if (info.sensorMask & ELOOPEMMER) {
    Serial.print(" ELE");
  }

  if (info.sensorMask & ELOOPPOMP) {
    Serial.print(" ELP");
  }

  if (info.sensorMask & POMP1) {
    Serial.print(" PO");
  }

  if (info.sensorMask & POMP2) {
    Serial.print(" PB");
  }

  if (info.sensorMask & EMMER1) {
    Serial.print(" EB");
  }

  if (info.sensorMask & EMMER2) {
    Serial.print(" EO");
  }

  Serial.println(" )");
}

//GETEST
bool containsChar(char *string, char character) {
  if (!(*string)) { //if string is empty
    return false;
  }

  else {
    return (*string == character || containsChar(string + 1, character));
  }
}

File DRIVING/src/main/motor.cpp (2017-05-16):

#include"motor.h"
#include<Arduino.h>
#include"pin.h"

Motor mainMotor(MAIN_MOTOR_FORWARDS_PIN, MAIN_MOTOR_BACKWARDS_PIN);
Motor emmerMotor(EMMER_MOTOR_FORWARDS_PIN, EMMER_MOTOR_BACKWARDS_PIN);
Motor pompMotor(POMP_MOTOR_FORWARDS_PIN, POMP_MOTOR_BACKWARDS_PIN);

Motor::Motor(int fPin, int bPin) : forwardPin(fPin), backwardPin(bPin) {
  pinMode(fPin, OUTPUT);
  pinMode(bPin, OUTPUT);
  speed = 0;
  power = 100;
}

//tussen -255 (achteruit, richting vuur) en 255 (vooruit richting bassin)
void Motor::SetSpeed(int newSpeed){
  Serial.println(newSpeed);
  if(newSpeed == GetSpeed()){
    return;
  }
  
  speed = newSpeed;
  outputToMotor();
}

int Motor::GetSpeed() {
  return speed;
}

void Motor::SetPower(unsigned int newPower) {
  if(newPower == GetPower()){
    return;
  }

  power = newPower % 101;
  
  outputToMotor();
}

unsigned int Motor::GetPower() {
  return power;
}

void Motor::outputToMotor(){
  //int outSpeed = mapSpeed();
  int outSpeed = speed;
  
  Serial.println(outSpeed);
  
  if(outSpeed < 0) {
    analogWrite(backwardPin, outSpeed * -1);
    analogWrite(forwardPin, 0);
  }
  else {
    analogWrite(backwardPin, 0);
    analogWrite(forwardPin, outSpeed);
  }
}

int Motor::mapSpeed(){
  return (speed * power) / 100;
}

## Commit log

2016-10-27 Robbe heeft de readme.md upgedatet
2016-10-27 nog een merge conflict opgelost
2016-11-04 iets aan het testen
2016-11-05 DRIVING: begonnen aan queue implementatie die moet helpen bij het filteren van metingen.
2016-11-05 queue getest op het eerste zicht in orde
2016-11-05 DRIVING: sensor directory met daarin sensor.ino en een geteste queue implementatie toegevoegd
2016-11-06 DRIVING: grote lijnen gedrag sensor geschreven.
2016-11-08 DRIVING: Queue implementatie met een array
2016-11-08 DRIVING: sensor.ino aangepast aan nieuwe queue
2016-11-08 Description empty bucket added
2016-11-09 Updaten van pump md
2016-11-11 DRIVING: werkende sensor met gemiddelde berekening
2017-02-13 Issue template
    Aanmaken van template voor het maken van Issues via Zenhub
2017-02-24 Inventor files upload
    [Frame.0001.ipt, Frame.ipt, VolledigGeassembleerdv001.0015.iam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]
2017-03-10 upload poempak delco image and updates 'kostenraming' and inventor files
    [Frame.0001.ipt, Frame.0002.ipt, Frame.ipt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]
2017-03-13 added distance sensors
2017-03-13 motor class added
2017-03-13 final version cost estimation which is going to be ordered today 13 March 2017
    [Materialenlijst totaal P. Delco 13032017.xlsx]
2017-03-13 bestandje met daarin overzicht welke pin voor wat gebruikt gaat worden
2017-03-13 added sensoren main opgeruimd pinout aangepast
2017-03-13 begonnen aan driving implementatie, bug uit Motor klasse gehaald
    [motor.cpp]
2017-03-13 Modified motorcontroller in Multisim and made a Ultiboard project. 3D PCB in directory 3D_MODELS
2017-03-14 alternatieve Graphset (die atm ook gevolgd wordt in de code)
2017-03-15 Motorcontroller versie 2
2017-03-16 Updated trace widths in Multisim
2017-03-16 header voor wireless comm aangevuld, addressen voor wireless comm gekozen.
2017-03-17 pump state verwijderd, meer wireless communicatie, pinout naam verandering
2017-03-17 werkend motorcontroller schema
2017-03-17 bug uit sensor.cpp gehaald, bug uit state overgangen gehaald
    [main.ino, sensors.cpp]
2017-03-17 motorcontroller schema werkend in multisim
2017-03-17 sensor defines verplaatst van h naar cpp
2017-03-21 vermogen motor veranderen past nu ook de huidige snelheid aan
2017-03-21 wireless kan nu commandos ontvangen, begin van command struct
2017-03-21 motor variabele naam verandering
2017-03-21 states directory hernoemt naar src zodat de relative path werkt
2017-03-24 added electric arduino switch circuit
2017-03-24 added motorcontroller circuit and changed pins
2017-03-24 gif animation of frame with dimensions
    [modelsWithDimensions.skp]
2017-03-27 motorcontrollerSchema gesaved
2017-03-27 cleaned up PCB
2017-03-27 export made
    [motorControllerPCB-1_0 - BoardOutline.gbr, motorControllerPCB-1_0 - BottomLayer.gbr, motorControllerPCB-1_0 - Drill Symbols-TopLayer-BottomLayer.gbr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]
2017-03-30 Revert "Merge branch 'master' of https://github.com/ccmteamap/robot"
    This reverts commit d90bde87612fd81ad69680d18a4015147d3471c8, reversing
    changes made to b05f91c60b41b73aacd5bc5c336f965dd7831cc5.
    [main.ino, sensors.cpp]
2017-03-31 parsed nu de commando's die in de wiki staan. pomp states klaar.
2017-03-31 kortste afstand wordt geselecteerd. waarde die uit versnellingsfunctie komt wordt omgezet naar int
2017-04-02 bugfixes, afstanden worden nu in cm getoond
    [client.ino]
2017-04-04 bugfix: motoren stopten niet als je de robot stopte of pauzeerde.\nbugfix: isValidMotorCommand keek de identifier niet na.
    [client.ino, main.ino, parser.cpp]
2017-04-04 manual state verwijderd. vergeten restje van een experimentje dat op niets uitdraaid
2017-04-07 BUGFIX: index serial buffer werd niet op nul gezet na verzending. code cleanup
    [client.ino, driving.cpp]
2017-04-08 bugfix ongedaan. was niet fout
    [client.ino]
2017-04-19 avoid merge conflict
    [modelsWithDimensions.skp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]
2017-04-25 pinnen in een aparte header, bugfix debug bitmask constanten in client
    [client.ino, debug.cpp, driving.cpp]
2017-05-05 sensor pinnen ingegeven, bug uit sensors.h
    [main.ino, pin.h, sensors.cpp]
2017-05-12 timer aan pomp motor toegevoegd
